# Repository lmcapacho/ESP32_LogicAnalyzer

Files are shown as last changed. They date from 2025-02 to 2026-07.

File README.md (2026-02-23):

# ESP32 LogicAnalyzer




A [SUMP](http://dangerousprototypes.com/docs/The_Logic_Sniffer%27s_extended_SUMP_protocol) compatible 16Bit Logic Analyzer for ESP32 MCUs.

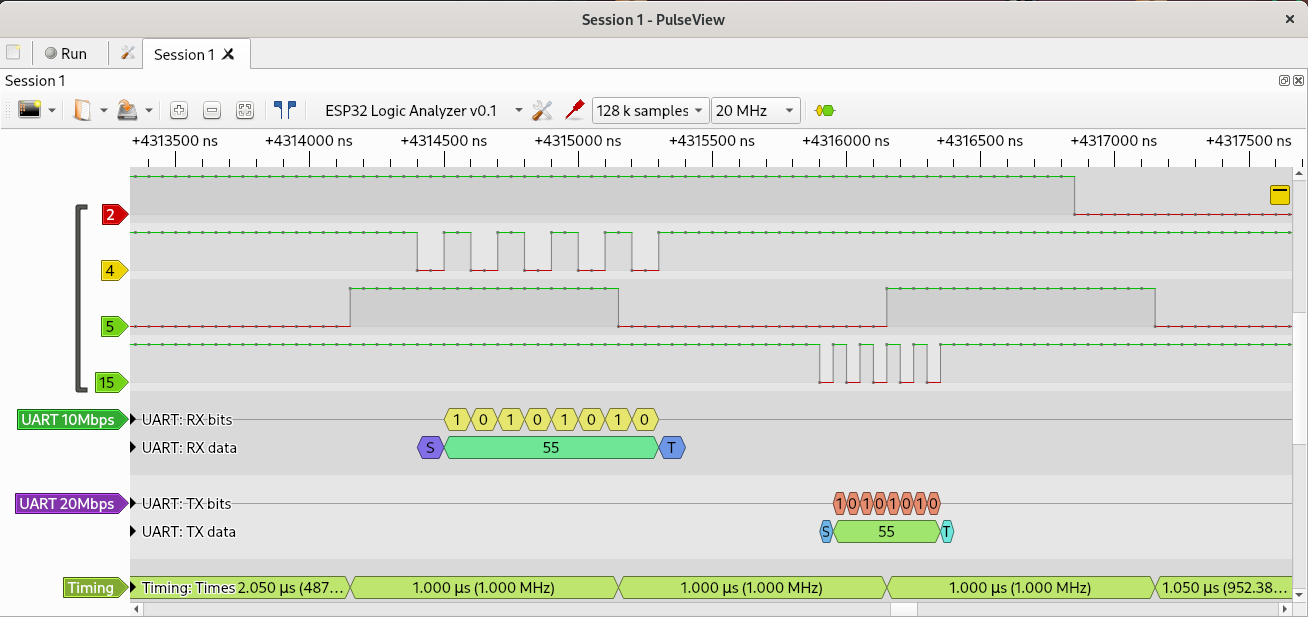
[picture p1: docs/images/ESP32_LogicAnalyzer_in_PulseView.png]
PulseView


## Specifications

- Uses **ESP32 I2S DMA** and can capture speeds up to **20 MHz**.
- Supports **8-bit** and **16-bit** operations.
- Maximum **128k** samples (even in 8-bit capturing mode).
- RLE compression supported.
- Default OLS port is **UART0** with a default baud rate of **912600**.
- You can configure UART ports and high-speed baud rates for OLS communication by editing the definitions in LogicAnalyzerConfig.h.

### Supported Environments

| Environment | Status | Details |
|---|---|---|
| PlatformIO | ✅ | Tested with `platform-espressif32@6.11.0` |
| Arduino IDE | ✅ | Tested with `Arduino-ESP32 core 3.3.7` |

### Under Development

- WROOVER modules support **2M** samples but only up to **2 MHz** due to bandwidth limits on PSRAM access.
- Analog input support.

## Quick Start Guide

### Environments

#### PlatformIO

1. Install [PlatformIO](https://platformio.org/) in VS Code.
2. Open the project folder in PlatformIO.
3. Build the project and flash it to your ESP32.

#### Arduino IDE

1. Install the **ESP32 board support** via the Boards Manager (`esp32 by Espressif Systems`).
2. Open the sketch in `ESP32_LogicAnalyzer/ESP32_LogicAnalyzer.ino`.
3. Select the board you're using (e.g. `ESP32 Dev Module`).
4. Use ESP32 Arduino core version `3.3.7`.
5. Click **Upload**.

**Important:** If you're using UART0 for OLS communication, set **Core Debug Level = None** in the Arduino IDE before compiling, especially for captures above 10 MHz.

### PulseView

Open PulseView with:
```bash
pulseview -D -d ols:conn=/dev/ttyUSB0::serialcomm=921600/8n1
```
Or from the GUI, connect the device and select **Openbench Logic Sniffer & SUMP compatibles (ols)**.

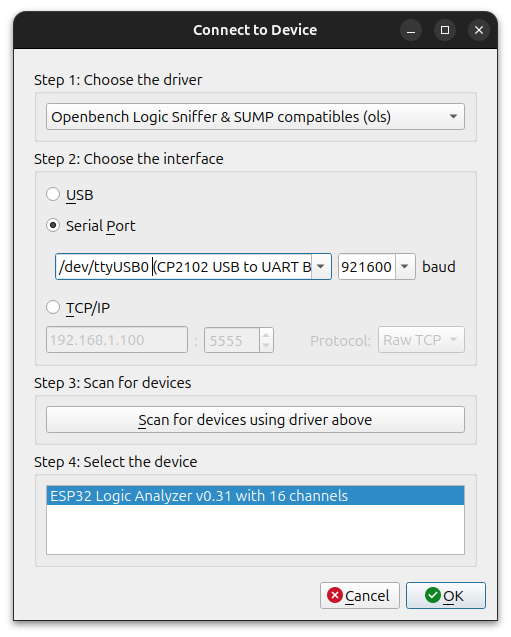
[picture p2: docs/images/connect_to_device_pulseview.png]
PulseView


RLE can be enabled in Device configuration dialog:

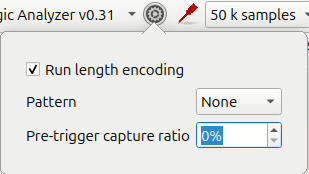
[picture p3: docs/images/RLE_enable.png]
RLE


For more details, see the [PulseView documentation](https://sigrok.org/wiki/PulseView).

## Connections

| Pin | Connection |
|---|---|
| clk_in | GPIO23 (connect to **clk_out**) |
| clk_out  | GPIO22 (connect to **clk_in**) |
| Ground | Connect the target device's GND to the ESP32 GND |
| Channels | CH15 - CH0 (connect your signals here)  |

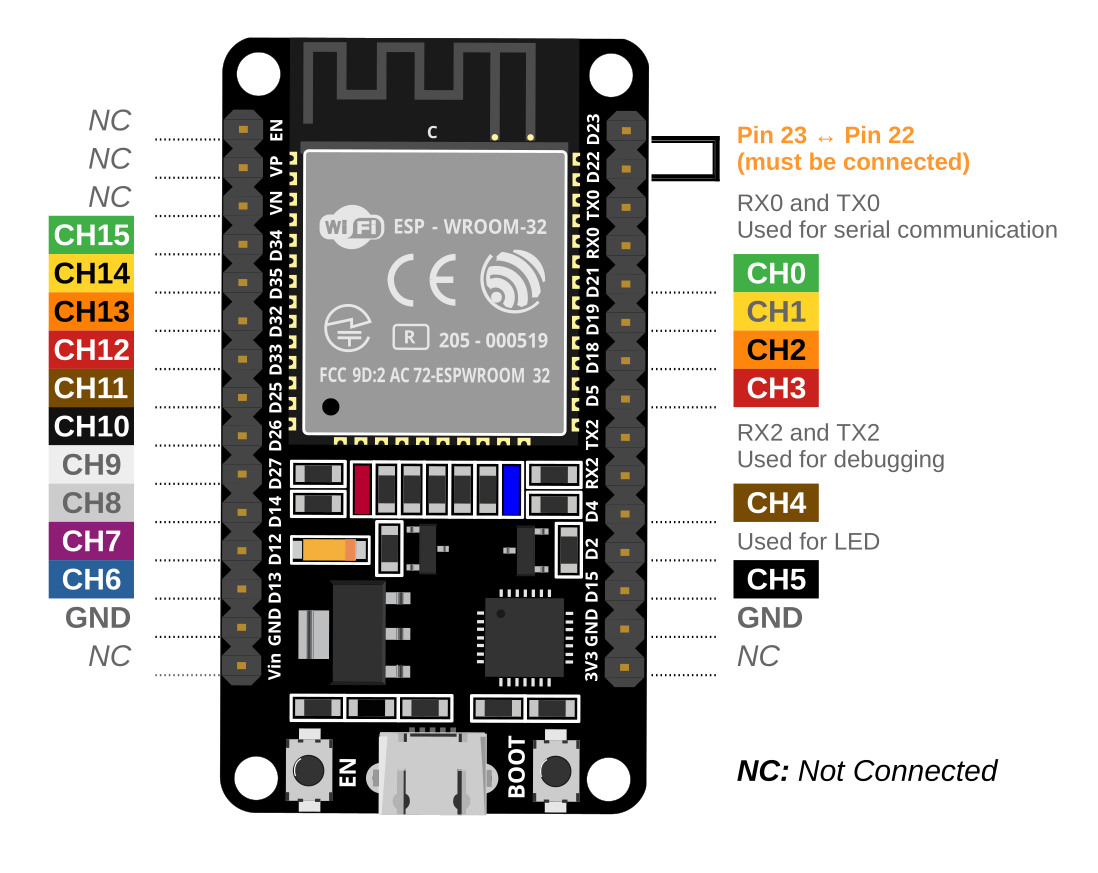
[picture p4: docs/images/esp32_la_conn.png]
ESP32LA Connection


⚠️ **Warning:** GPIO23 is used for I2S input clock and GPIO22 for LEDC output clock.  
Do not use these pins for general I/O. If needed, change them in the code and rewire accordingly.

## Hardware Design (KiCad)

This project includes a custom PCB designed in **KiCad 9** to connect the ESP32 DevKitC V1 with logic analyzer channels and level shifters.

All hardware-related files are located in the [`hardware/`](./hardware) folder and include:

- Complete KiCad project (`.kicad_pro`, `.kicad_sch`, `.kicad_pcb`)
- BOM (`BOM.xlsx`) and CPL (`CPL1.xlsx`) for assembly
- Gerber files (`hardware/gerbers/`) for PCB fabrication
- Optional UART2 debug port
- Level shifter ICs (SN74LVC245A) for 5V input compatibility

> ⚠️ The design is currently under validation. Use at your own risk until physical tests are completed.

### PCB Preview

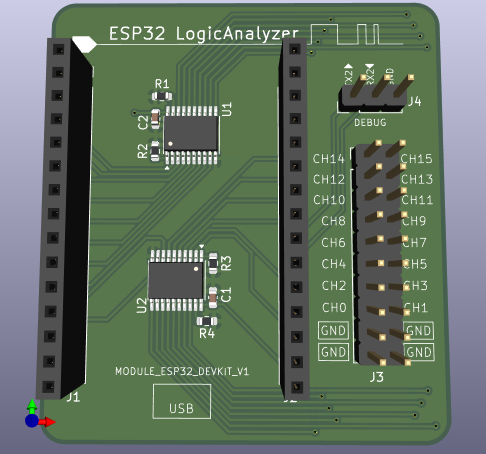
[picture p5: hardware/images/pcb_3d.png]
3D View of PCB


## Attributions

This project is a fork of [ESP32_LogicAnalyzer](https://github.com/EUA/ESP32_LogicAnalyzer), created by [Erdem U. Altinyurt](https://github.com/EUA).

This project uses code from:
- [esp32-cam-demo](https://github.com/igrr/esp32-cam-demo) for I2S DMA.
- [Arduino Logic Analyzer](https://github.com/gillham/logic_analyzer) as a SUMP protocol "template".

## License

This project is licensed under the **GPL 3.0 License**. See the [LICENSE](LICENSE) file for details.

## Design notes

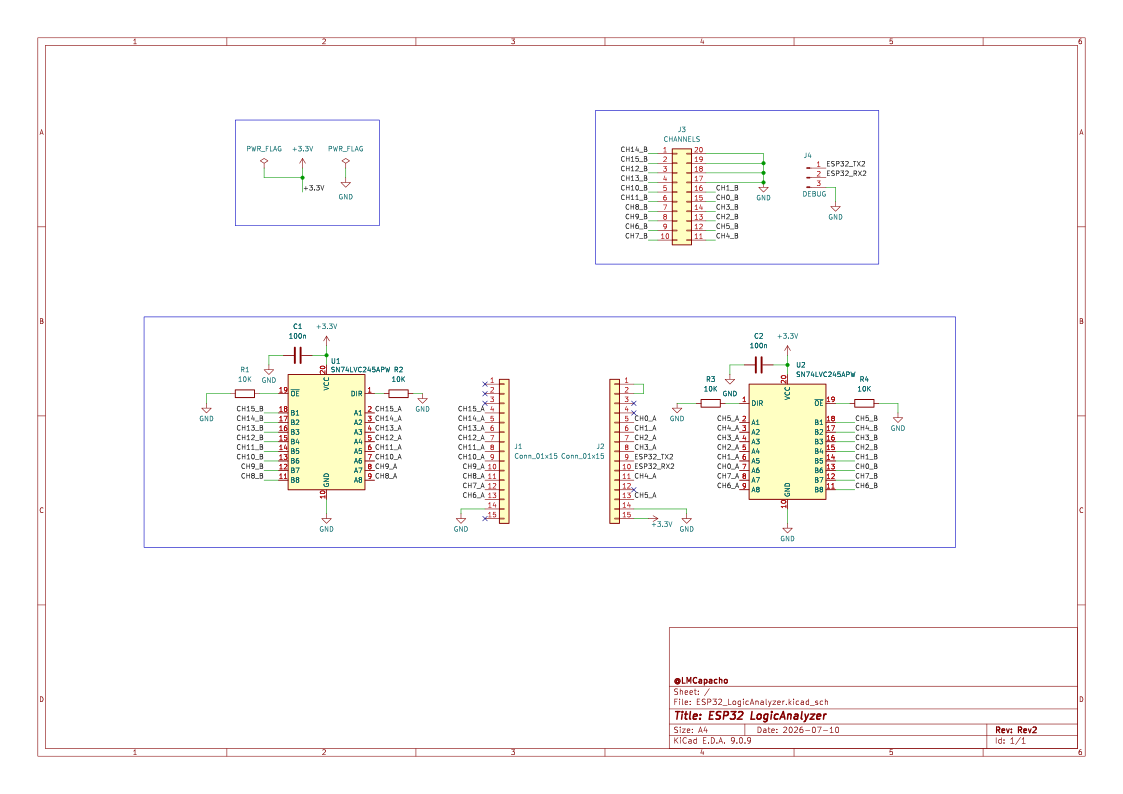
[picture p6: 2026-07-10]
hardware/images/schematic.png

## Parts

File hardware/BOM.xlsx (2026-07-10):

Comment | Designator | Footprint | JLCPCB Part #（optional）
100n | C1,C2 | C_0603_1608Metric | C14663
10K | R1,R2,R3,R4 | R_0603_1608Metric | C101254
CHANNELS | J3 | PinHeader_2x10_P2.54mm_Vertical | C5116480
Conn_01x15 | J1,J2 | PinSocket_1x15_P2.54mm_Vertical | C7499333
DEBUG | J4 | PinHeader_1x03_P2.54mm_Vertical | C2937625
SN74LVC245APW | U1,U2 | TSSOP-20_4.4x6.5mm_P0.65mm | C7848

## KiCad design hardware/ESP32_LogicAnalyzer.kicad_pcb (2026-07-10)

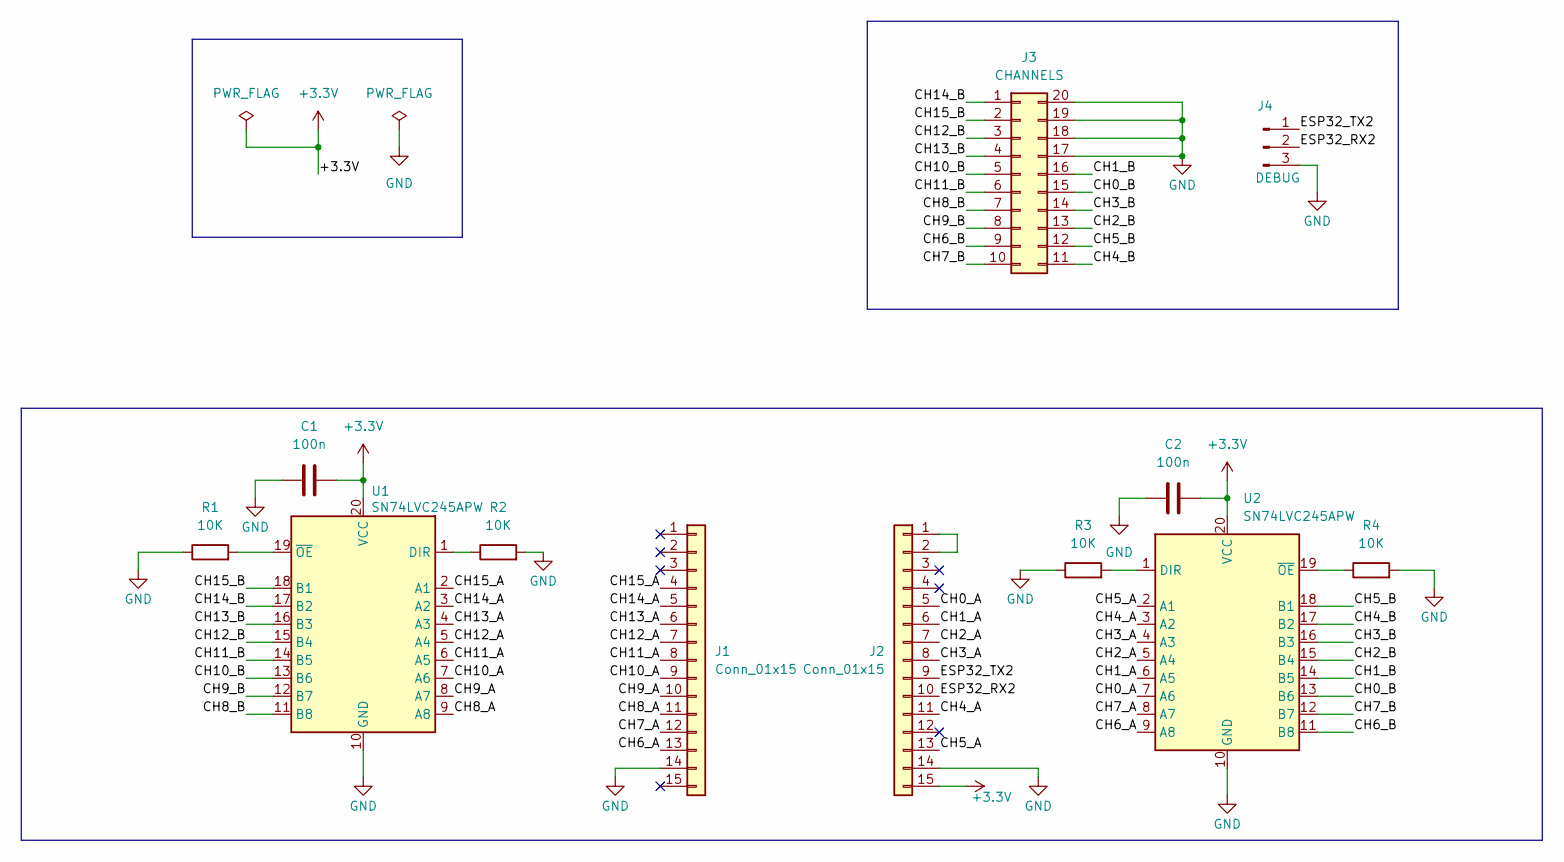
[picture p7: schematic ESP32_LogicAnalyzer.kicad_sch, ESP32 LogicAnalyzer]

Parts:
C1, C2: 100n; C_0603_1608Metric
J1, J2: Conn_01x15; PinSocket_1x15_P2.54mm_Vertical
J3: CHANNELS; PinHeader_2x10_P2.54mm_Vertical
J4: DEBUG; PinHeader_1x03_P2.54mm_Vertical
R1, R2, R3, R4: 10K; R_0603_1608Metric
U1, U2: SN74LVC245APW; TSSOP-20_4.4x6.5mm_P0.65mm

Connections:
+3.3V: C1.2, C2.2, J2.15, U1.20 (VCC), U2.20 (VCC)
/CH0_A: J2.5, U2.7 (A6)
/CH0_B: J3.15, U2.13 (B6)
/CH1_A: J2.6, U2.6 (A5)
/CH1_B: J3.16, U2.14 (B5)
/CH2_A: J2.7, U2.5 (A4)
/CH2_B: J3.13, U2.15 (B4)
/CH3_A: J2.8, U2.4 (A3)
/CH3_B: J3.14, U2.16 (B3)
/CH4_A: J2.11, U2.3 (A2)
/CH4_B: J3.11, U2.17 (B2)
/CH5_A: J2.13, U2.2 (A1)
/CH5_B: J3.12, U2.18 (B1)
/CH6_A: J1.13, U2.9 (A8)
/CH6_B: J3.9, U2.11 (B8)
/CH7_A: J1.12, U2.8 (A7)
/CH7_B: J3.10, U2.12 (B7)
/CH8_A: J1.11, U1.9 (A8)
/CH8_B: J3.7, U1.11 (B8)
/CH9_A: J1.10, U1.8 (A7)
/CH9_B: J3.8, U1.12 (B7)
/CH10_A: J1.9, U1.7 (A6)
/CH10_B: J3.5, U1.13 (B6)
/CH11_A: J1.8, U1.6 (A5)
/CH11_B: J3.6, U1.14 (B5)
/CH12_A: J1.7, U1.5 (A4)
/CH12_B: J3.3, U1.15 (B4)
/CH13_A: J1.6, U1.4 (A3)
/CH13_B: J3.4, U1.16 (B3)
/CH14_A: J1.5, U1.3 (A2)
/CH14_B: J3.1, U1.17 (B2)
/CH15_A: J1.4, U1.2 (A1)
/CH15_B: J3.2, U1.18 (B1)
/ESP32_RX2: J2.10, J4.2
/ESP32_TX2: J2.9, J4.1
GND: C1.1, C2.1, J1.14, J2.14, J3.17, J3.18, J3.19, J3.20, J4.3, R1.1, R2.2, R3.1, R4.2, U1.10 (GND), U2.10 (GND)
unnamed: J2.1, J2.2
unnamed: R2.1, U1.1 (DIR)
unnamed: R1.2, U1.19 (~OE)
unnamed: R3.2, U2.1 (DIR)
unnamed: R4.1, U2.19 (~OE)

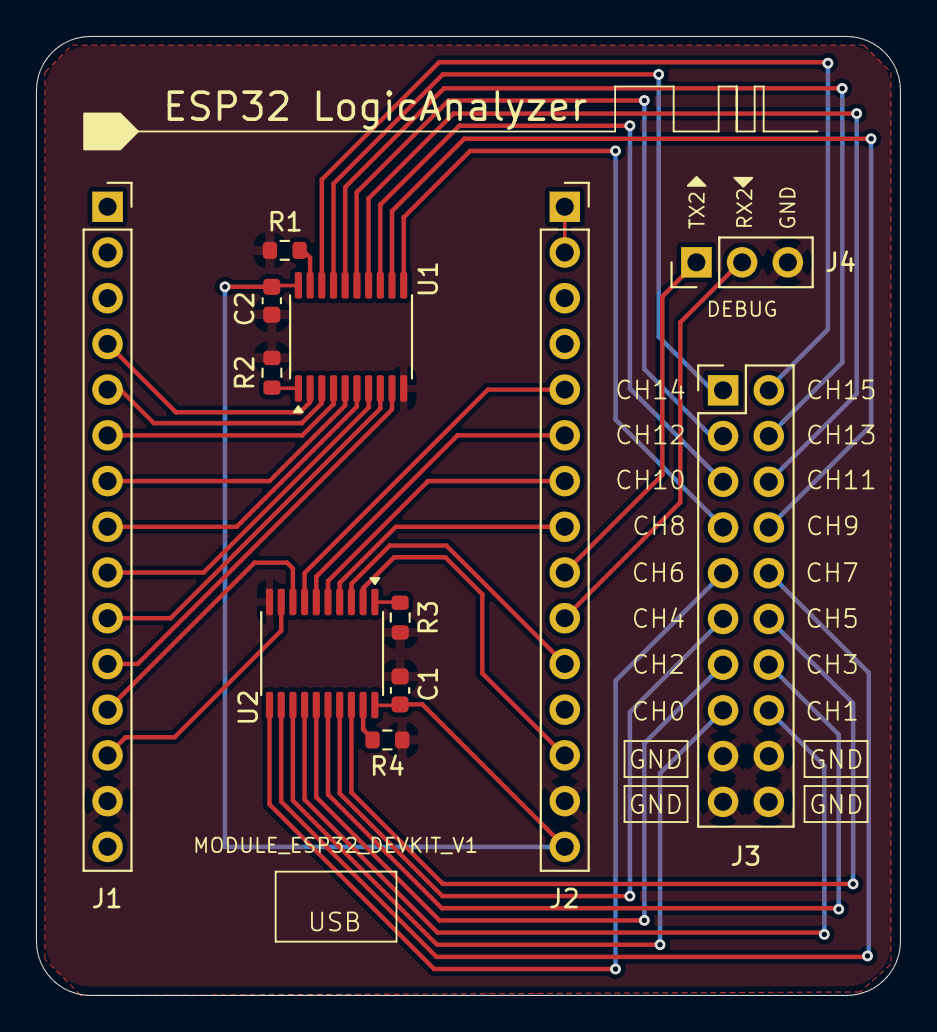
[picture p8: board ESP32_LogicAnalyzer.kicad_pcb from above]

Board: 2 copper layers, 48.0 x 53.3 mm, 12 parts (0 on the bottom side), 41 nets.

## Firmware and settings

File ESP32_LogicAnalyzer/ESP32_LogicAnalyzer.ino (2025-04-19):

  /*************************************************************************
 * 
 *  ESP32 Logic Analyzer
 *  Copyright (C) 2025 lmcapacho (Luis Miguel Capacho V.)  
 *  Copyright (C) 2020 Erdem U. Altinyurt
 *    
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
 *************************************************************************
 *
 *  This project steals some code from 
 *  https://github.com/igrr/esp32-cam-demo for I2S DMA
 *  and
 *  https://github.com/gillham/logic_analyzer/issues for SUMP protocol as template.
 * 
 */ 
#include "LogicAnalyzer.h"

LogicAnalyzer esp32la;

void setup(void) {
  esp32la.begin();
}

void loop()
{
  vTaskDelay(1); //To avoid WDT
  
  if (OLS_Port.available() > 0) {
    int cmdByte = OLS_Port.read();
    esp32la.handleCommand(cmdByte);    
  }
}

void IRAM_ATTR i2s_wrapper(void *arg)
{
  esp32la.i2s_isr(arg);
}

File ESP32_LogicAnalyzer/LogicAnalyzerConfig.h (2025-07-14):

#ifndef LOGIC_ANALYZER_CONFIG_H
#define LOGIC_ANALYZER_CONFIG_H

#define TAG "esp32la"

// Uncomment to enable debug output (uses Serial_Debug_Port)
//#define _DEBUG_MODE_

// ========================================
// OLS Port and Serial Debug Configuration
// ========================================

#ifdef _DEBUG_MODE_
  #define OLS_Port Serial2
  #define OLS_Port_Baud 3000000

  #define Serial_Debug_Port Serial
  #define Serial_Debug_Port_Baud 921600
#else
  #define OLS_Port Serial   
  #define OLS_Port_Baud 921600
#endif

// ==========================
// Compression configuration
// ==========================

/*
 * ALLOW_ZERO_RLE:
 * ---------------
 * ALLOW_ZERO_RLE 1 is Fast mode.
 *  Add RLE Count 0 to RLE stack for non repeated values and postpone the RLE processing so faster.
 *      8Bit Mode : ~28.4k clock per 4k block, captures 3000us while inspecting ~10Mhz clock at 20Mhz mode
 *      16Bit Mode : ~22.3k clock per 4k block, captures 1500us while inspecting ~10Mhz clock at 20Mhz mode
 * 
 * ALLOW_ZERO_RLE 0 is Slow mode.
 *  Just RAW RLE buffer. It doesn't add 0 count values for non-repeated RLE values and process flags on the fly, 
 *  so little slow but efficient.
 *      8Bit Mode : ~34.7k clock per 4k block, captures 4700us while inspecting ~10Mhz clock at 20Mhz mode
 *      16Bit Mode : ~30.3k clock per 4k block, captures 2400us while inspecting ~10Mhz clock at 20Mhz mode
 */
#define ALLOW_ZERO_RLE 0

// ==============================
// Capture Settings
// ==============================

#define CAPTURE_SIZE      128000   // total number of samples
#define RLE_BUFFER_SIZE    96000   // buffer size for compressed data

// ==============================
// Pin Assignments
// ==============================

#define LED_PIN 2  // LED lights up while capturing

// Channel input pins
#define CH0_PIN   21
#define CH1_PIN   19
#define CH2_PIN   18
#define CH3_PIN   5
#define CH4_PIN   4
#define CH5_PIN   15
#define CH6_PIN   13
#define CH7_PIN   12
#define CH8_PIN   14
#define CH9_PIN   27
#define CH10_PIN  26
#define CH11_PIN  25
#define CH12_PIN  33
#define CH13_PIN  32
#define CH14_PIN  35
#define CH15_PIN  34

// Clock and sync lines
#define CLK_OUT 22
#define CLK_IN  23

#endif // LOGIC_ANALYZER_CONFIG_H

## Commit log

2025-02-14 fix: change channel 10 from GPIO20 to GPIO25 to avoid bootloop
    [ESP32_LogicAnalyzer.ino]
2025-02-22 refactor: change LED pin port to onboard LED
2025-02-23 refactor: order pin channels for better organization
2025-04-16 chore: include Arduino.h in header and remove redundant includes
2025-04-16 refactor: move function prototypes from .ino to header file
2025-04-16 style: rename ledPin to LED_PIN to follow constant naming convention
2025-04-18 refactor: rename camera_state_t to logic_analyzer_state_t
2025-04-18 refactor: reorder ESP32_LogicAnalyzer.h
2025-04-18 refactor: rename ESP32_LogicAnalyzer to LogicAnalyzer and create class structure
2025-04-18 refactor: rename ESP32_LogicAnalyzer_I2S_DMA.ino to LogicAnalyzer_I2S_DMA.cpp and move functions into class
2025-04-19 fix: add missing headers for Arduino IDE
    [LogicAnalyzer.h]
2025-04-19 fix: add version check for ESP_ARDUINO_VERSION_MAJOR to support 2.x and 3.x
    [LogicAnalyzer.cpp]
2025-04-19 chore: reorganize repo structure for Arduino IDE and PlatformIO compatibility
2025-04-19 refactor: replace global TAG variable with define
    [LogicAnalyzer.h, LogicAnalyzerConfig.h]
2025-07-14 docs: update channel diagram to reflect new CH0–CH5 mapping
2025-07-14 refactor: reorder CH0–CH5 pins to match updated mapping
2025-08-07 chore: add initial PCB hardware design files using KiCad
    [BOM.xlsx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]
2025-08-08 docs: add hardware section to README for KiCad PCB design
2026-02-23 chore: improve gitignore for PlatformIO, VSCode and KiCad
2026-07-10 Update ESP32 PCB hardware files
    [BOM.xlsx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]

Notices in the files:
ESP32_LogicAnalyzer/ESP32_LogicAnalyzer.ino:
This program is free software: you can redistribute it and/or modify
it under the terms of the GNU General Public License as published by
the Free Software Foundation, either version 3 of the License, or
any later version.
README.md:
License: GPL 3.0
